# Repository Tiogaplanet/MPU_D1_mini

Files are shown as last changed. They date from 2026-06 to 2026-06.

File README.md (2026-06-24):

# MiP D1 mini pack
A [D1 mini](https://wiki.wemos.cc/products:d1:d1_mini) adapter board for [WowWee Labs'](https://github.com/WowWeeLabs/) [MiP](https://wowwee.com/mip) robot.  Similar to the [MiP ProMini Pack](https://github.com/adamgreen/MiP_ProMini-Pack), this board adapts the D1 mini and compatible boards to MiP.  Either install the D1 mini pack in a pair of pin headers or solder it directly to the board and you'll be programming MiP to connect to the Internet in no time.

## Acknowledgment
* As always, a big "thank you" goes out to [adamgreen](https://github.com/adamgreen/).  Without his help I'd still be wondering why my MiP won't talk to an Arduino.  Now, it's talking to the Internet!
* I'd also like to thank [Casey Kuhns](https://github.com/caseykuhns) who while at [SparkFun](https://github.com/sparkfun) developed the original [ProMini Pack](https://github.com/sparkfun/mip_promini-pack) and the [ProtoPack](https://github.com/sparkfun/mip_proto-pack) which provided the foundation for this project.

## OSH Park renderings
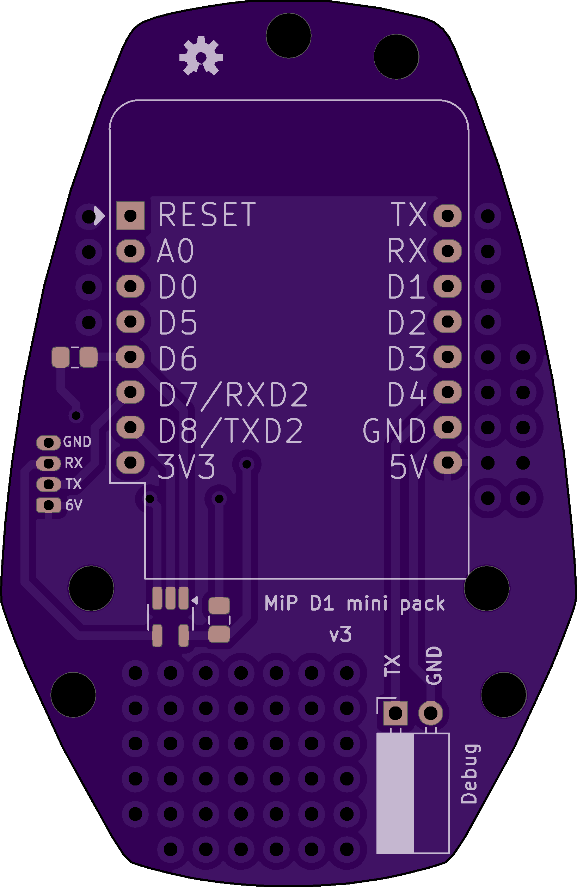
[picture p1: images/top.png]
The top of the MiP D1 mini pack


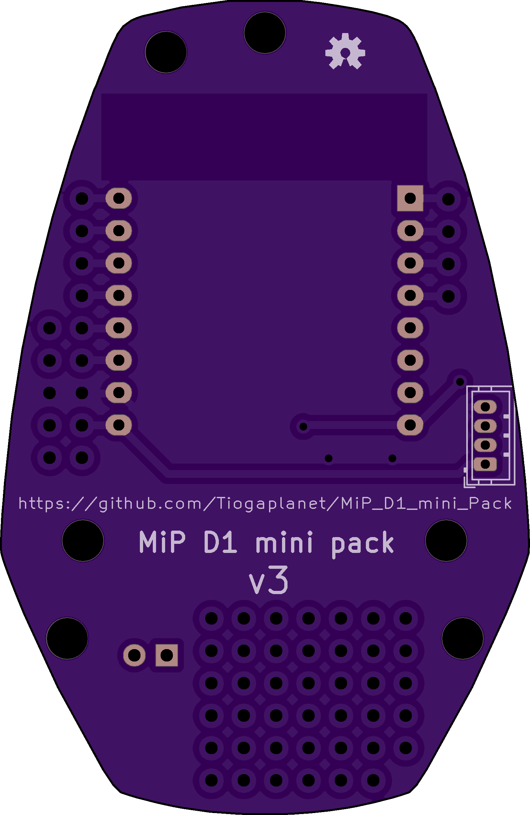
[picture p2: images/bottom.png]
The bottom of the MiP D1 mini pack


## Installation
Please see the [wiki](https://github.com/Tiogaplanet/MiP_D1-mini_pack/wiki) for up-to-date installation instructions.

## Disclaimer
I am a hobbyiest sharing this designed-at-home board with fans of robotics, MiP and the ESP8266 wifi chip.  While I strive to make this board as useful and "right" as it can be, in no way shall I be responsible for any damage that may occur to your MiP or D1 mini either incidently or directly through the use of this board.  You use this board at your own risk.

If you are experienced in robotics or circuit design and spot something that can or should be improved, please review [CONTRIBUTING.md](https://github.com/Tiogaplanet/MiP_D1-mini_pack/blob/master/CONTRIBUTING.md) and submit a pull request.

## License
Shield: [][cc-by-sa]

This work is licensed under a
[Creative Commons Attribution-ShareAlike 4.0 International License][cc-by-sa].

[][cc-by-sa]

[cc-by-sa]: http://creativecommons.org/licenses/by-sa/4.0/
[cc-by-sa-image]: https://licensebuttons.net/l/by-sa/4.0/88x31.png
[cc-by-sa-shield]: https://img.shields.io/badge/License-CC%20BY--SA%204.0-lightgrey.svg

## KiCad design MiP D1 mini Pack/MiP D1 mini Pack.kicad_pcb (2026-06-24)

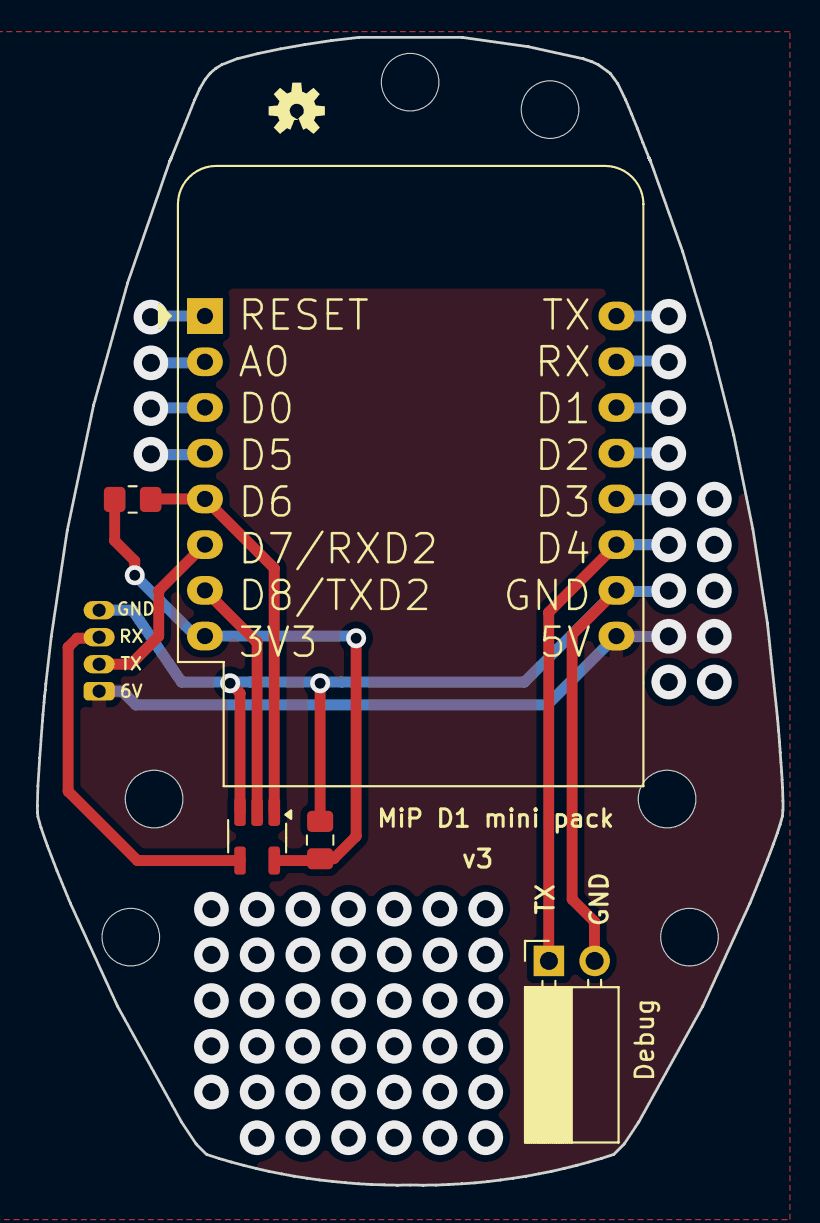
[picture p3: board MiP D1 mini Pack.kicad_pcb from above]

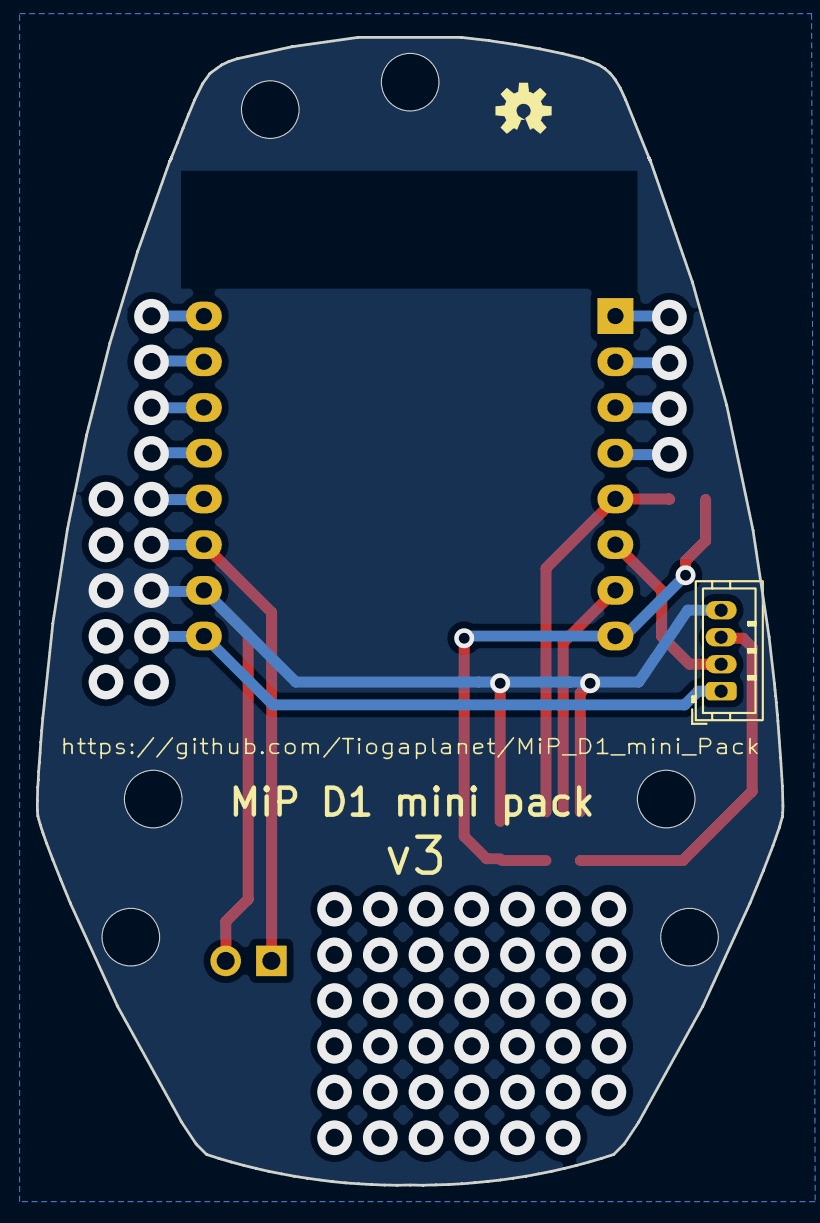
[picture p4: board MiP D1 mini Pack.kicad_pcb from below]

Board: 2 copper layers, 41.4 x 63.8 mm, 15 parts (2 on the bottom side), 7 nets.

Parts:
C1: .1μF; C_0805_2012Metric_Pad1.18x1.45mm_HandSolder
FRAME1: FRAME-LETTER; CREATIVE_COMMONS
J1: MiP; JST_ZH_B4B-ZR_1x04_P1.50mm_Vertical
J2: Debug; PinSocket_1x02_P2.54mm_Horizontal
LOGO2, LOGO2#2: OSHW-LOGOS; OSHW-LOGO-S
R1: 10K; R_0805_2012Metric_Pad1.20x1.40mm_HandSolder
U1: WEMOS D1 mini; WEMOS_D1_mini_light
U2: 74LVC1G125; SOT-23-5_HandSoldering
UNK_HOLE_0: dummyfp0
UNK_HOLE_1: dummyfp1
UNK_HOLE_2: dummyfp2
UNK_HOLE_3: dummyfp3
UNK_HOLE_4: dummyfp4
UNK_HOLE_5: dummyfp5

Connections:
+3V3: C1.1, R1.2, U1.8 (3V3), U2.5 (VCC_5)
+6V: J1.1, U1.9 (5V)
/BUF_TX: J1.3, U2.4
/D1_TX: U1.7 (CS/D8), U2.2
/Debug: J2.1 (Pin_1_1), U1.11 (D4)
/RX: J1.2, U1.6 (MOSI/D7)
unnamed: R1.1, U1.5 (MISO/D6), U2.1

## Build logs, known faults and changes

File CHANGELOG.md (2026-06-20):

# Change Log

All notable changes to this project will be documented in this file.
 
## [Unreleased v3] - as of 20 June 2026
  
Version 3 fixes a bug that prevents the D1 mini from booting during periods of programming and reboot.
The workaround has been to disconnect the USB cable connecting the D1 mini to the computer after 
flashing the program onto the D1 mini.
 
### Added
 
### Changed
  
- Migrated project from Eagle 7.7.0 to KiCAD.
 
### Fixed
 
- [GPIO15 Bootstrapping Trap](https://github.com/Tiogaplanet/MiP_D1-mini-Pack/issues/1)
  The D1 mini occassionally hangs on reboot during program-and-test cycles due to 
  GPIO15 being pulled high.  Problem solved with 10KΩ resistor.
 
## [v2] - 2018
   
### Changed
- Corrected the serial port wiriring and added silkscreening to explain pin layout.

### Fixed
 
- The unreleased v1 board had the serial port wired incorrectly.

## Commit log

2026-06-20 Updated board images
    Updated the OSH Park renderings of the top and bottom of the board.
2026-06-20 Schematic cleanup
    Renamed the connector references to account for the lost J1 and J2 from the v2 board. Moved things around a bit.
    [MiP D1 mini Pack.kicad_pcb, MiP D1 mini Pack.kicad_sch]
2026-06-24 Updated pdf of schematic
    [MiP D1 mini Pack-B_Cu.gbr, MiP D1 mini Pack-B_Mask.gbr, MiP D1 mini Pack-B_Silkscreen.gbr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]
2026-06-24 Remove title case
    [MiP D1 mini Pack.kicad_pcb]
2026-06-24 More title case
    Not sure I even like calling it a "pack"
    [MiP D1 mini Pack.kicad_pcb]
2026-06-24 Upload v3 board images
2026-06-24 Added BOM data to project file
    ignore xls files
    [MiP D1 mini Pack.kicad_sch]

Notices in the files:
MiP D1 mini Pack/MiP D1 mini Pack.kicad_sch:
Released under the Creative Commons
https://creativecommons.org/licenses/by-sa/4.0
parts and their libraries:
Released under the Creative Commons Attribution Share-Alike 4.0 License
